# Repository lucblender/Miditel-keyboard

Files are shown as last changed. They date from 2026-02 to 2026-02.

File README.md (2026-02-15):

# MIDITEL, a MIDI keyboard using a Minitel keyboard

Finished Product

# Description

The Miditel is a Midi keyboard built with a Mini-tel keyboard. The key layout is inspired by an accordion keyboard. Its features are highly inspired by the Arturia Keystep including Normal play, sequencer, or arpeggiator. In addition, it embedded a small Oled screen and give unique a multi-sequencer feature

**The project is based on the MINITEL 1.**

# Hardware

You will need a miditel 1 keyboard with a working keyboard matrix, the PCB which can be found in the [hardware/PCB](hardware/PCB), an 1.3 inch [OLED Display module by waveshare](https://www.waveshare.com/1.3inch-oled-module-c.htm)

# Software

The project run on a raspberry pico 1 with micropython. To this date, it is working under v1.27.0. Download latest micropython image on [Micropython website](https://micropython.org/download/RPI_PICO/).

You then need to transfer .py files and .pbm (pictures) files on the little fs of the pico. All the .py files, all the .pbm files and the folder arp_mode with all its .pbm files.
Here is what the structure should look like.

- arp_mode
  - dwn.pbm
  - dwnx2.pbm
  - ...
- arial6.py
- arial8.py
- arial10.py
- font6.py
- font10.py
- keyboardConfiguration.py
- main.py
- OLED_SPI.py
- writer.py
- lxb64x64.pbm
- pause.pbm
- play.pbm
- rec.pbm
- stop.pbm

## About Minitel

Remove the keyboard from your minitel. You will then connect the ribbon cable of the minitel to a serie of wire and then to J3, the 17 pins connector on the PCB. All the info about the minitel keyboard and its matrix can be found on [entropie.org](https://entropie.org/3615/index.php/2020/08/05/le-clavier-du-minitel-1b/)

## Manufacturing Files

### PCB

The PCB to control the miditel files can be found in the [hardware/PCB](hardware/PCB) folder. I personnaly used [PCBWay](https://www.pcbway.com) service to produce the PCB.

The PCB is as simple double sided PCB.

### Front panel

The manufacturing files of the front panel can be found in the [hardware/FrontPanel](hardware/FrontPanel) folder. It has been made to cnc machine and laser engrave a front panel. They can also be easily converted to make the front panel of a PCB which is a cheaper option.
The Front panel is composed of the following files:

- Top_Platev004 files : the front panel with the cutout
- Top_Plate_design-only : only the "aestetic" part
- Top_Plate_outer_shape : only the "cutout" part

In my original design, the front panel has been made using [PCBWay](https://www.pcbway.com) Sheet Metal Fabrication service. I chose bead-blasted copper with custom laser engraving to fit the color of the Minitel Keyboard.

### 3D printed parts

The manufacturing files of the front panel can be found in the [hardware/3DPrinting](hardware/3DPrinting) folder.

- Bottom_Platev004.3mf : bottom plate that hold the PCB and is glued directly on the minitel
- Wheelv004.3mf : wheel to put on the potentiometers
- paint stencil folder : 3d printable stencil to paint white and black square on the key of the minitel

### LICENSE

[CC BY-NC-SA](https://creativecommons.org/licenses/by-nc-sa/4.0/)

This license enables reusers to distribute, remix, adapt, and build upon the material in any medium or format for noncommercial purposes only, and only so long as attribution is given to the creator. If you remix, adapt, or build upon the material, you must license the modified material under identical terms. CC BY-NC-SA includes the following elements:

BY: credit must be given to the creator.
NC: Only noncommercial uses of the work are permitted.
SA: Adaptations must be shared under the same terms.

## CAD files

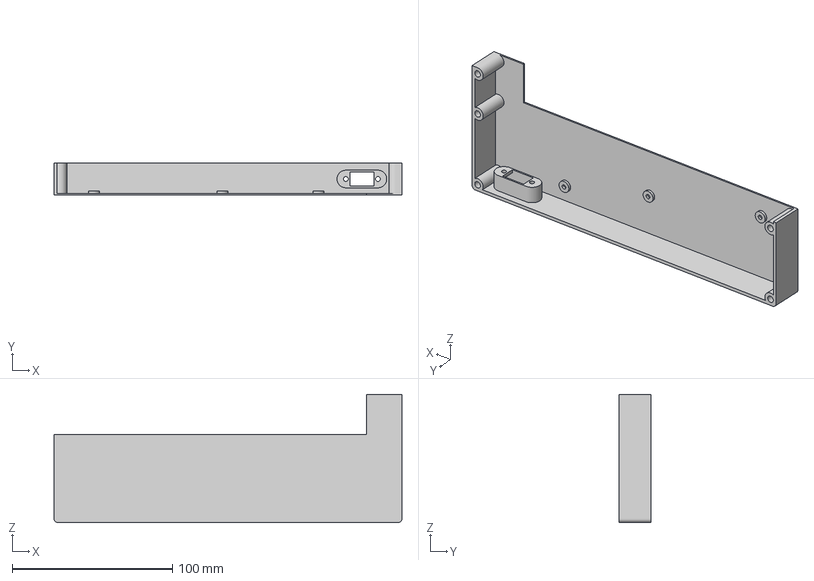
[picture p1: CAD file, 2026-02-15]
hardware/3DPrinting/Bottom_Platev004.3mf
217.0 x 20.0 x 80.0 mm

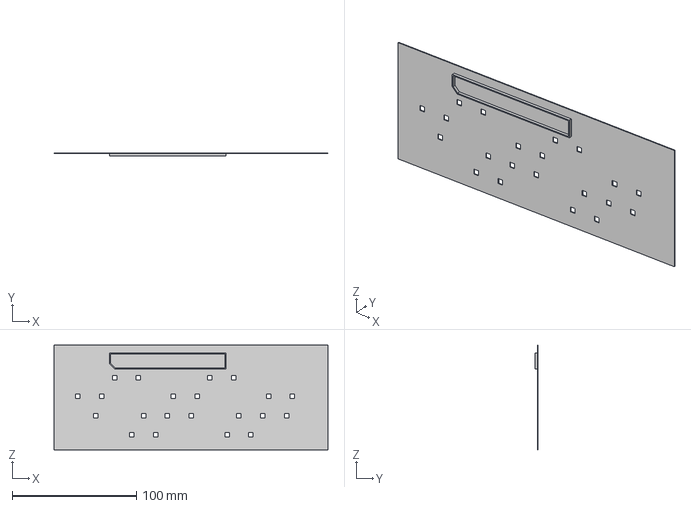
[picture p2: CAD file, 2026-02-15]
hardware/3DPrinting/paint stencil/white_keys_v001.3mf
220.8 x 2.60 x 84.5 mm

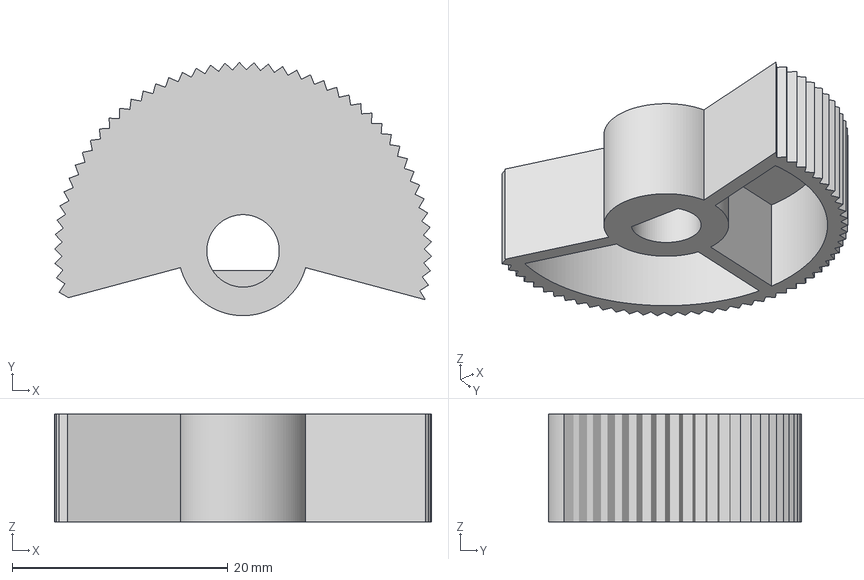
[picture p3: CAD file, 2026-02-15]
hardware/3DPrinting/Wheelv004.3mf
34.9 x 23.5 x 10.0 mm

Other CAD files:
hardware/FrontPanel/Top_Platev004.step
hardware/3DPrinting/paint stencil/black_keys_v001.3mf
hardware/FrontPanel/Top_Plate_design-only_v004.dxf
hardware/FrontPanel/Top_Platev004_outer_shape.dxf
hardware/FrontPanel/Top_Platev004.dxf

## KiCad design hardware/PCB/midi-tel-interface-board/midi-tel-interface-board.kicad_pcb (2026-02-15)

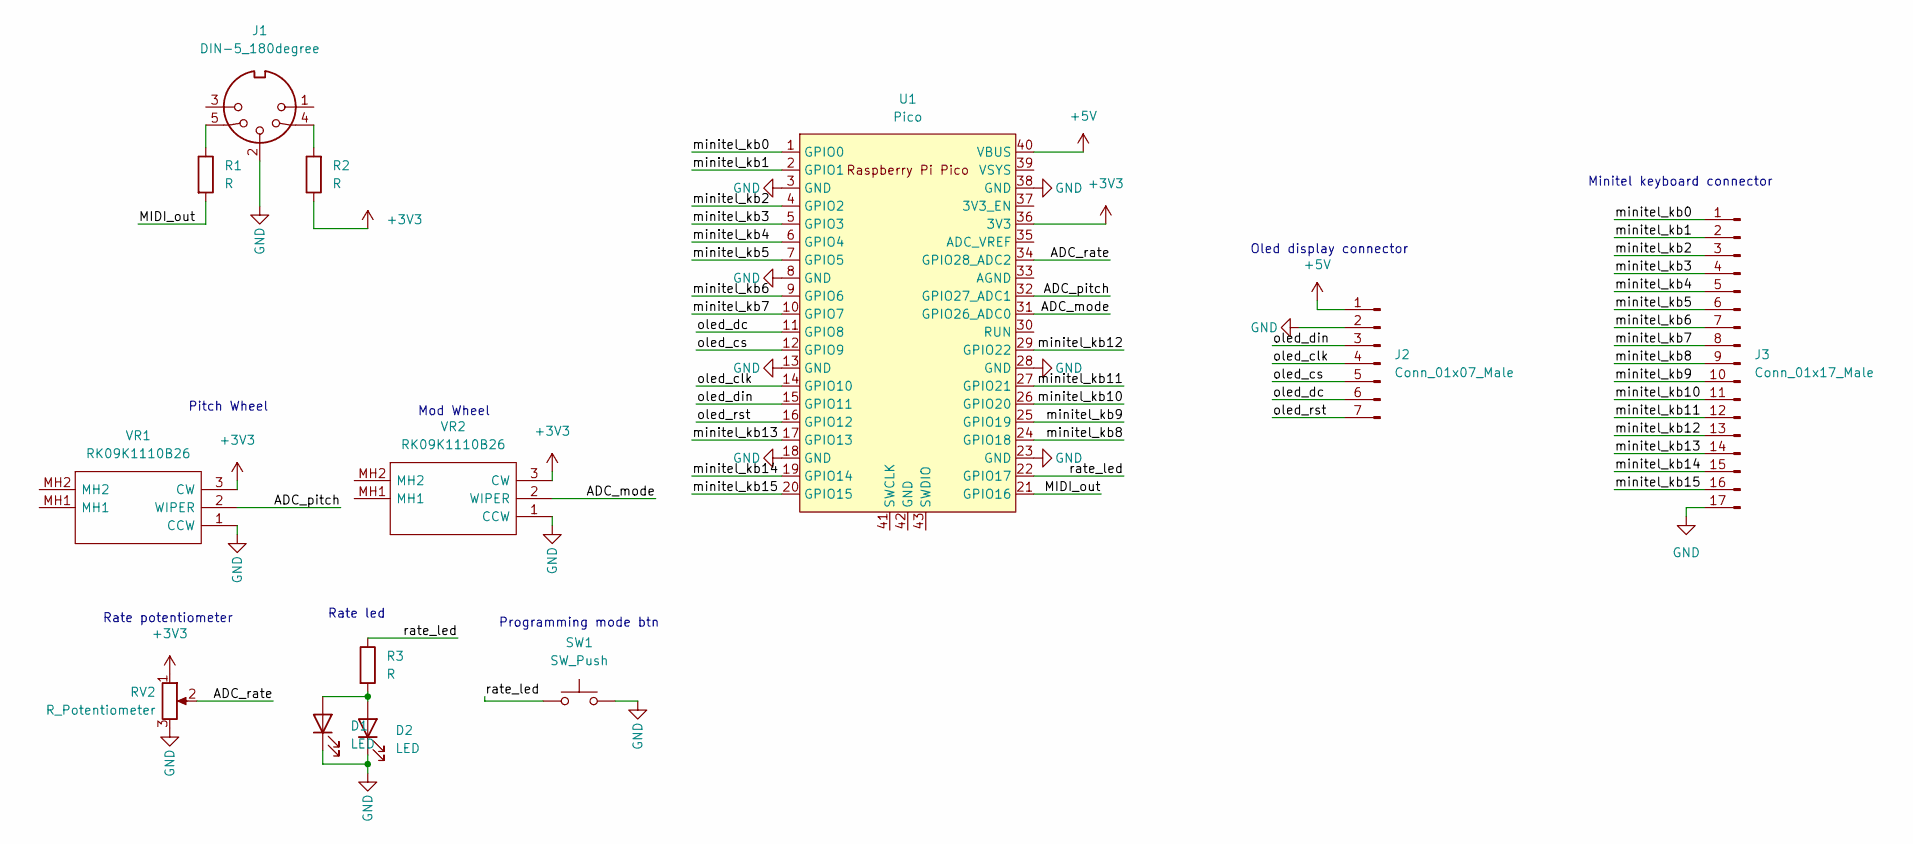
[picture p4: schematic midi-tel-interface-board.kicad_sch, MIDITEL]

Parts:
D1: LED; LED_D3.0mm
D2: LED; LED_0603_1608Metric
J1: DIN-5_180degree; 52120441
J2: Conn_01x07_Male; PinHeader_1x07_P2.54mm_Vertical
J3: Conn_01x17_Male; PinHeader_1x17_P2.54mm_Vertical
R1, R2, R3: R; R_0805_2012Metric
RV2: R_Potentiometer; Potentiometer_Alpha_RD901F-40-00D_Single_Vertical
SW1: SW_Push; SW_PUSH_6mm
U1: Pico; RPi_Pico_SMD_TH
VR1, VR2: RK09K1110B26; Mouser Part Number 688-RK09K1110B26

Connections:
+3V3: R2.1, RV2.1, U1.36 (3V3), VR1.3 (CW), VR2.3 (CW)
+5V: J2.1, U1.40 (VBUS)
/ADC_mode: U1.31 (GPIO26_ADC0), VR2.2 (WIPER)
/ADC_pitch: U1.32 (GPIO27_ADC1), VR1.2 (WIPER)
/ADC_rate: RV2.2, U1.34 (GPIO28_ADC2)
/MIDI_out: R1.2, U1.21 (GPIO16)
/minitel_kb0: J3.1, U1.1 (GPIO0)
/minitel_kb1: J3.2, U1.2 (GPIO1)
/minitel_kb2: J3.3, U1.4 (GPIO2)
/minitel_kb3: J3.4, U1.5 (GPIO3)
/minitel_kb4: J3.5, U1.6 (GPIO4)
/minitel_kb5: J3.6, U1.7 (GPIO5)
/minitel_kb6: J3.7, U1.9 (GPIO6)
/minitel_kb7: J3.8, U1.10 (GPIO7)
/minitel_kb8: J3.9, U1.24 (GPIO18)
/minitel_kb9: J3.10, U1.25 (GPIO19)
/minitel_kb10: J3.11, U1.26 (GPIO20)
/minitel_kb11: J3.12, U1.27 (GPIO21)
/minitel_kb12: J3.13, U1.29 (GPIO22)
/minitel_kb13: J3.14, U1.17 (GPIO13)
/minitel_kb14: J3.15, U1.19 (GPIO14)
/minitel_kb15: J3.16, U1.20 (GPIO15)
/oled_clk: J2.4, U1.14 (GPIO10)
/oled_cs: J2.5, U1.12 (GPIO9)
/oled_dc: J2.6, U1.11 (GPIO8)
/oled_din: J2.3, U1.15 (GPIO11)
/oled_rst: J2.7, U1.16 (GPIO12)
/rate_led: R3.1, SW1.1, U1.22 (GPIO17)
GND: D1.1 (K), D2.1 (K), J1.2, J2.2, J3.17, RV2.3, SW1.2, U1.3 (GND), U1.8 (GND), U1.13 (GND), U1.18 (GND), U1.23 (GND), U1.28 (GND), U1.38 (GND), VR1.1 (CCW), VR2.1 (CCW)
unnamed: D1.2 (A), D2.2 (A), R3.2
unnamed: J1.4, R2.2
unnamed: J1.5, R1.1

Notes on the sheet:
Mod Wheel
Oled display connector
Programming mode btn
Rate led
Rate potentiometer
Pitch Wheel
Minitel keyboard connector

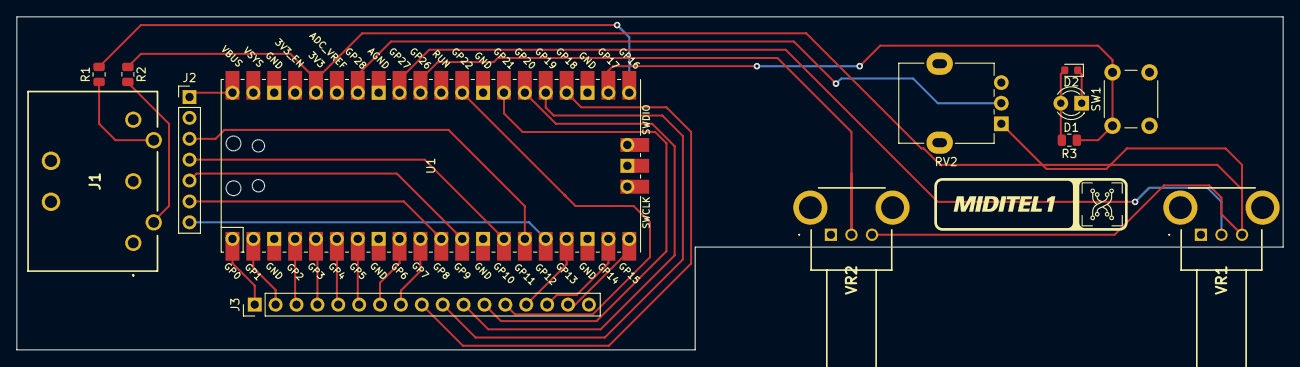
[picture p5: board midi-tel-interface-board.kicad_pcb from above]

Board: 2 copper layers, 154.0 x 40.5 mm, 13 parts (0 on the bottom side), 32 nets.

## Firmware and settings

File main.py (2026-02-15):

import machine
from machine import Pin
import utime
import time
import _thread

from keyboardConfiguration import KeyboardConfiguration, append_error
from OLED_SPI import OLED_1inch3

from machine import freq
freq(250_000_000, 250_000_000)

boot_exit_button = Pin(17, Pin.IN, Pin.PULL_UP)
rate_potentiometer = machine.ADC(28)
pitch_potentiometer = machine.ADC(27)
mod_potentiometer = machine.ADC(26)

COL_NUMBER = 8
ROW_NUMBER = 8

MAX_DELAY_BEFORE_SCREENSAVER_S = 300
last_key_update = time.time()


# 0 1 2 3 4 5 6 7 8 9 10 11 12 13 14 15
# F E D C B A 9 8 7 6 5  4  3  2  1  0

# line = 1  2  3  4  B C D E
#        14 13 12 11 4 3 2 1

# col =  0  5  6 7 8 9 A F
#        15 10 9 8 7 6 5 0


# 8 9  10 11 12
# 22 21 20 19 18

col_list_pin = [15, 20, 21, 22, 7, 6, 5, 0]
row_list_pin = [14, 13, 18, 19, 4, 3, 2, 1]
# invertedd col_list_pin=[0,5,6,7,22,21,20,15]
# inverted row_list_pin=[1,2,3,4,19,18,13,14]
row_list = [0, 0, 0, 0, 0, 0, 0, 0]
col_list = [0, 0, 0, 0, 0, 0, 0, 0]

smooth_rate_potentiometer = -1
smooth_mod_potentiometer = -1
smooth_pitch_potentiometer = -1

for x in range(0, ROW_NUMBER):
    row_list[x] = Pin(row_list_pin[x], Pin.OUT)
    row_list[x].value(1)


for x in range(0, COL_NUMBER):
    col_list[x] = Pin(col_list_pin[x], Pin.IN, Pin.PULL_UP)

key_map = [
    ["up", "t", "g", ".", "b", "guide", "Fnct", "connexion fin"],
    ["correction", "e", "d", "Esc", "c", "z", "s", "x"],
    ["annulation", "r", "f", ",", "v", "a", "q", "w"],
    ["down", "y", "h", "'", "n", "sommaire", "Ctrl", "espace"],
    ["shift", ";", "*", "suite", "0", "u", "j", "#"],
    ["left", "-", "7", "retour", "8", "i", "k", "9"],
    ["right", ":", "4", "envoi", "5", "o", "l", "6"],
    ["enter", "?", "1", "répétition", "2", "p", "m", "3"]
]

note_map = [
    [0, 65, 67, 60, 69, 0, 0, 0],
    [0, 59, 61, 54, 63, 56, 58, 60],
    [0, 62, 64, 57, 66, 53, 55, 57],
    [0, 68, 70, 63, 72, 0, 52, 0],
    [54, 66, 0, 0, 0, 71, 73, 0],
    [0, 69, 0, 0, 0, 74, 76, 0],
    [0, 72, 0, 0, 0, 77, 79, 0],
    [0, 75, 0, 0, 0, 80, 82, 0]
]

key_state = [[0, 0, 0, 0, 0, 0, 0, 0], [0, 0, 0, 0, 0, 0, 0, 0], [0, 0, 0, 0, 0, 0, 0, 0], [0, 0, 0, 0, 0, 0, 0, 0], [
    0, 0, 0, 0, 0, 0, 0, 0], [0, 0, 0, 0, 0, 0, 0, 0], [0, 0, 0, 0, 0, 0, 0, 0], [0, 0, 0, 0, 0, 0, 0, 0]]
key_state_old = [[0, 0, 0, 0, 0, 0, 0, 0], [0, 0, 0, 0, 0, 0, 0, 0], [0, 0, 0, 0, 0, 0, 0, 0], [0, 0, 0, 0, 0, 0, 0, 0], [
    0, 0, 0, 0, 0, 0, 0, 0], [0, 0, 0, 0, 0, 0, 0, 0], [0, 0, 0, 0, 0, 0, 0, 0], [0, 0, 0, 0, 0, 0, 0, 0]]

keyboard_config = KeyboardConfiguration()
OLED = OLED_1inch3(keyboard_config)
keyboard_config.set_display(OLED)


def KeypadRead(cols, rows):
    global key_state
    global key_state_old
    global last_key_update
    global OLED

    key_state = [[0, 0, 0, 0, 0, 0, 0, 0], [0, 0, 0, 0, 0, 0, 0, 0], [0, 0, 0, 0, 0, 0, 0, 0], [0, 0, 0, 0, 0, 0, 0, 0], [
        0, 0, 0, 0, 0, 0, 0, 0], [0, 0, 0, 0, 0, 0, 0, 0], [0, 0, 0, 0, 0, 0, 0, 0], [0, 0, 0, 0, 0, 0, 0, 0]]

    for r in range(0, ROW_NUMBER):
        # put pin as output
        Pin(row_list_pin[r], Pin.OUT)
        rows[r].value(0)
        for c in range(0, COL_NUMBER):
            if cols[c].value() == 0:
                key_state[r][c] = 1

            if (key_state[r][c] != key_state_old[r][c]):
                last_key_update = time.time()
                if OLED.is_screensaver() == True:
                    OLED.reset_screensaver_mode()
                key = key_map[r][c]
                note = note_map[r][c]
                if key_state[r][c] == 0:
                    if (note != 0):
                        keyboard_config.note_off(
                            note+keyboard_config.octave_offset*12)
                    else:
                        customKeyOff(key)
                else:
                    if (note != 0):
                        keyboard_config.note_on(
                            note+keyboard_config.octave_offset*12)
                    else:
                        customKeyOn(key)
        # put pin as input to have high z
        Pin(row_list_pin[r], Pin.IN)

    for x in range(0, COL_NUMBER):
        for y in range(0, ROW_NUMBER):
            key_state_old[x][y] = key_state[x][y]


print("--- Ready to get user inputs ---")


def customKeyOn(key):
    global octaveOffset
    if key == "right":
        keyboard_config.incr_octave_offset()
    elif key == "left":
        keyboard_config.decr_octave_offset()
    if key == "up":
        keyboard_config.incr_mode()
    elif key == "down":
        keyboard_config.decr_mode()
    elif key == "guide":
        keyboard_config.rec_pressed()
    elif key == "correction":
        keyboard_config.stop_pressed()
    elif key == "suite":
        keyboard_config.pauseplay_pressed()
    elif key == "envoi":
        keyboard_config.load_seq_pressed()
    elif key == "enter":
        keyboard_config.blank_tile_pressed()
    elif key == "sommaire":
        keyboard_config.midi_channel_gate_length_pressed()
    elif key == "#":
        keyboard_config.sharp_pressed()
    elif key == "*":
        keyboard_config.star_pressed()
    elif key == "annulation":
        keyboard_config.clear_seq_hold_pressed()
    elif key == "retour":
        keyboard_config.decr_arp_mode_kbp_transpose()
    elif key == "répétition":
        keyboard_config.incr_arp_mode_undo_seq()
    elif key == "connexion fin":
        keyboard_config.change_time_div_pressed()
    elif key == "espace":
        keyboard_config.note_on(69)  # play A4 440Hz
    elif key.isdigit():
        keyboard_config.digit_pressed(int(key))


def customKeyOff(key):
    if key == "espace":
        keyboard_config.note_off(69)


def refresh_screen_loop():
    global OLED
    index = 0
    while True:
        if OLED.is_screensaver() == True:
            index += 1
            if index % 16 == True:
                OLED.update_screensaver()
                index = 0
        elif (OLED.need_refresh_flag == True):
            OLED.display()
        time.sleep(0.01)


if boot_exit_button.value() == 1:
    try:
        OLED.display_helixbyte()
        time.sleep(0.5)
        keyboard_config.set_led(Pin(17, Pin.OUT))
        keyboard_config.display()
        _thread.start_new_thread(refresh_screen_loop, ())
        OLED.need_screen_refresh()

        while True:
            if time.time() - last_key_update > MAX_DELAY_BEFORE_SCREENSAVER_S and OLED.is_screensaver() == False:
                OLED.set_screensaver_mode()

            key = KeypadRead(col_list, row_list)
            if smooth_rate_potentiometer == -1:
                smooth_rate_potentiometer = (
                    65536-rate_potentiometer.read_u16())
            else:
                smooth_rate_potentiometer = smooth_rate_potentiometer * \
                    0.8 + 0.2*(65536-rate_potentiometer.read_u16())

            if smooth_mod_potentiometer == -1:
                smooth_mod_potentiometer = (65536-mod_potentiometer.read_u16())
            else:
                smooth_mod_potentiometer = smooth_mod_potentiometer * \
                    0.5 + 0.5*(65536-mod_potentiometer.read_u16())

            if smooth_pitch_potentiometer == -1:
                smooth_pitch_potentiometer = (
                    65536-pitch_potentiometer.read_u16())
            else:
                smooth_pitch_potentiometer = smooth_pitch_potentiometer * \
                    0.5 + 0.5*(65536-pitch_potentiometer.read_u16())

            keyboard_config.set_rate_potentiometer(smooth_rate_potentiometer)
            keyboard_config.set_pitch_potentiometer(smooth_pitch_potentiometer)
            keyboard_config.set_mod_potentiometer(smooth_mod_potentiometer)
    except Exception as e:
        keyboard_config.deinit_timer()
        append_error(e)
else:
    keyboard_config.deinit_timer()
    OLED.display_helixbyte()
    time.sleep(0.5)
    OLED.display_programming_mode()
    print("Exit button pressed at boot, quit program")

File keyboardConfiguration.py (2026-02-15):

import machine
from machine import Pin, Timer
import ustruct
from random import randrange
import json

MIN_BPM = 30
MAX_BPM = 240

LEN_INDEX = -1

POT_MAX_VALUE = 42000
POT_MIN_VALUE = 24000
POT_INTERVAL_VALUE = POT_MAX_VALUE-POT_MIN_VALUE

# Lookup tables for O(1) performance instead of if-elif chains
# Indexed by TimeDiv enum values
TIME_DIV_TO_SPLIT = (24, 16, 12, 8, 6, 4, 3, 2)
TIME_DIV_TO_STR = ("1/4", "1/4T", "1/8", "1/8T",
                   "1/16", "1/16T", "1/32", "1/32T")
MODE_TO_STR = ("Basic", "Arpeg", "Sequ", "Multi\nsequencer")
ARP_MODE_TO_STR = ("Up", "Down", "Inclusive", "Exclusive",
                   "Random", "Press Order", "Up x2", "Down x2")
PLAY_MODE_TO_STR = ("⏵", "⏸", "⏺", "⏹")


def enum(**enums: int):
    return type('Enum', (), enums)


Mode = enum(BASIC=0, ARPEGIATOR=1, SEQUENCER=2, MULTISEQUENCER=3)

TimeDiv = enum(ONE_FOURTH=0,
               ONE_FOURTH_T=1,
               ONE_EIGHTH=2,
               ONE_EIGHTH_T=3,
               ONE_SIXTEENTH=4,
               ONE_SIXTEENTH_T=5,
               ONE_THIRTYSECOND=6,
               ONE_THIRTYSECOND_T=7)


PlayMode = enum(PLAYING=0,
                PAUSING=1,
                RECORDING=2,
                STOPPED=3)

ArpMode = enum(UP=0,
               DWN=1,
               INC=2,
               EXC=3,
               RAND=4,
               ORDER=5,
               UPX2=6,
               DWNX2=7,
               )


def modeToStr(local_mode):
    return MODE_TO_STR[local_mode]


def timeDivToStr(local_time_div):
    return TIME_DIV_TO_STR[local_time_div]


def timeDivToTimeSplit(local_time_div):
    return TIME_DIV_TO_SPLIT[local_time_div]


def arpModeToStr(local_arp_mode):
    return ARP_MODE_TO_STR[local_arp_mode]


def sort_notes_for_arp_mode(local_arp_mode, arp_notes):
    to_return = []
    cpy_arp_notes = list(arp_notes)

    if local_arp_mode == ArpMode.UP:
        cpy_arp_notes.sort()
        to_return = cpy_arp_notes
    elif local_arp_mode == ArpMode.DWN:
        cpy_arp_notes.sort()
        cpy_arp_notes.reverse()
        to_return = cpy_arp_notes
    elif local_arp_mode == ArpMode.INC:
        cpy_arp_notes.sort()
        rev_cpy_arp_notes = list(cpy_arp_notes)
        rev_cpy_arp_notes.reverse()
        to_return = cpy_arp_notes+rev_cpy_arp_notes
    elif local_arp_mode == ArpMode.EXC:
        cpy_arp_notes.sort()
        rev_cpy_arp_notes = list(cpy_arp_notes)
        rev_cpy_arp_notes.reverse()
        to_return = cpy_arp_notes+rev_cpy_arp_notes[1:-1]
    # in random, the index of the note played will be random, the array doesn't change
    elif local_arp_mode == ArpMode.RAND:
        to_return = cpy_arp_notes
    elif local_arp_mode == ArpMode.ORDER:
        to_return = cpy_arp_notes
    elif local_arp_mode == ArpMode.UPX2:
        cpy_arp_notes.sort()
        for x in cpy_arp_notes:
            to_return.append(x)
            to_return.append(x)
    elif local_arp_mode == ArpMode.DWNX2:
        cpy_arp_notes.sort()
        cpy_arp_notes.reverse()
        for x in cpy_arp_notes:
            to_return.append(x)
            to_return.append(x)
    return to_return


def playModeToStr(local_play_mode):
    return PLAY_MODE_TO_STR[local_play_mode]


def midi_to_key(note_num):
    notes = ["C", "C#", "D", "D#", "E", "F", "F#", "G", "G#", "A", "A#", "B"]
    octave = (note_num // 12) - 1
    key = notes[note_num % 12] + str(octave)
    return key


def append_error(error):
    print("*-"*20)
    print("Error caught")
    print(error)
    print("*-"*20)
    error_file = open("error.txt", "a")
    error_file.write(str(error))
    error_file.write("\n")
    error_file.close()


def decomp(n):
    L = dict()
    k = 2
    while n != 1:
        exp = 0
        while n % k == 0:
            n = n // k
            exp += 1
        if exp != 0:
            L[k] = exp
        k = k + 1
    return L


def _ppcm(a, b):
    Da = decomp(a)
    Db = decomp(b)
    p = 1
    for facteur, exposant in Da.items():
        if facteur in Db:
            exp = max(exposant, Db[facteur])
        else:
            exp = exposant
        p *= facteur**exp
    for facteur, exposant in Db.items():
        if facteur not in Da:
            p *= facteur**exposant
    return p


def ppcm(L):
    while len(L) > 1:
        a = L[-1]
        L.pop()
        b = L[-1]
        L.pop()
        L.append(_ppcm(a, b))
    return L[0]


"""
if self.mode == Mode.BASIC:
    pass
elif self.mode == Mode.SEQUENCER:
    pass
elif self.mode == Mode.ARPEGIATOR:
    pass
"""
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

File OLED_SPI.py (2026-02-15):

from machine import Pin, SPI
import framebuf
import time
from keyboardConfiguration import *
import arial6
import arial8
import arial10
import font10
import font6
import writer
from random import randrange

DC = 8
RST = 12
MOSI = 11
SCK = 10
CS = 9


def pict_to_fbuff(path, x, y):
    with open(path, 'rb') as f:
        f.readline()  # Magic number
        f.readline()  # Creator comment
        f.readline()  # Dimensions
        data = bytearray(f.read())
    return framebuf.FrameBuffer(data, x, y, framebuf.MONO_HLSB)


class OLED_1inch3(framebuf.FrameBuffer):
    def __init__(self, keyboard_config):
        self.width = 128
        self.height = 64

        self.need_refresh_flag = False

        self.screensaver_active = False
        self.screesaver_pixels = [[0]*2]*20

        self.cs = Pin(CS, Pin.OUT)
        self.rst = Pin(RST, Pin.OUT)

        self.cs(1)
        self.spi = SPI(1)
        self.spi = SPI(1, 4_000_000)
        self.spi = SPI(1, 4_000_000, polarity=0, phase=0,
                       sck=Pin(SCK), mosi=Pin(MOSI), miso=None)
        self.dc = Pin(DC, Pin.OUT)
        self.dc(1)
        self.buffer = bytearray(self.height * self.width // 8)
        super().__init__(self.buffer, self.width, self.height, framebuf.MONO_HMSB)
        self.init_display()

        self.white = 0xffff
        self.black = 0x0000

        self.keyboard_config = keyboard_config

        self.font_writer_arial6 = writer.Writer(self, arial6)
        self.font_writer_arial8 = writer.Writer(self, arial8)
        self.font_writer_arial10 = writer.Writer(self, arial10)
        self.font_writer_font10 = writer.Writer(self, font10)
        self.font_writer_font6 = writer.Writer(self, font6)

        self.fbuf_play = pict_to_fbuff('play.pbm', 9, 9)
        self.fbuf_pause = pict_to_fbuff('pause.pbm', 9, 9)
        self.fbuf_rec = pict_to_fbuff('rec.pbm', 9, 9)
        self.fbuf_stop = pict_to_fbuff('stop.pbm', 9, 9)

        self.fbufs_play_mode = [self.fbuf_play,
                                self.fbuf_pause, self.fbuf_rec, self.fbuf_stop]

        self.fbuf_arp_up = pict_to_fbuff('arp_mode/up.pbm', 16, 16)
        self.fbuf_arp_dwn = pict_to_fbuff('arp_mode/dwn.pbm', 16, 16)
        self.fbuf_arp_inc = pict_to_fbuff('arp_mode/inc.pbm', 16, 16)
        self.fbuf_arp_exc = pict_to_fbuff('arp_mode/exc.pbm', 16, 16)
        self.fbuf_arp_rand = pict_to_fbuff('arp_mode/rand.pbm', 16, 16)
        self.fbuf_arp_order = pict_to_fbuff('arp_mode/order.pbm', 16, 16)
        self.fbuf_arp_upx2 = pict_to_fbuff('arp_mode/upx2.pbm', 16, 16)
        self.fbuf_arp_dwnx2 = pict_to_fbuff('arp_mode/dwnx2.pbm', 16, 16)

        self.fbufs_arp_modes = [self.fbuf_arp_up, self.fbuf_arp_dwn, self.fbuf_arp_inc, self.fbuf_arp_exc,
                                self.fbuf_arp_rand, self.fbuf_arp_order, self.fbuf_arp_upx2, self.fbuf_arp_dwnx2]

        self.fbuf_inv_arp_up = pict_to_fbuff('arp_mode/inv_up.pbm', 16, 16)
        self.fbuf_inv_arp_dwn = pict_to_fbuff('arp_mode/inv_dwn.pbm', 16, 16)
        self.fbuf_inv_arp_inc = pict_to_fbuff('arp_mode/inv_inc.pbm', 16, 16)
        self.fbuf_inv_arp_exc = pict_to_fbuff('arp_mode/inv_exc.pbm', 16, 16)
        self.fbuf_inv_arp_rand = pict_to_fbuff('arp_mode/inv_rand.pbm', 16, 16)
        self.fbuf_inv_arp_order = pict_to_fbuff(
            'arp_mode/inv_order.pbm', 16, 16)
        self.fbuf_inv_arp_upx2 = pict_to_fbuff('arp_mode/inv_upx2.pbm', 16, 16)
        self.fbuf_inv_arp_dwnx2 = pict_to_fbuff(
            'arp_mode/inv_dwnx2.pbm', 16, 16)

        self.fbufs_inv_arp_modes = [self.fbuf_inv_arp_up, self.fbuf_inv_arp_dwn, self.fbuf_inv_arp_inc, self.fbuf_inv_arp_exc,
                                    self.fbuf_inv_arp_rand, self.fbuf_inv_arp_order, self.fbuf_inv_arp_upx2, self.fbuf_inv_arp_dwnx2]

    def write_cmd(self, cmd):
        self.cs(1)
        self.dc(0)
        self.cs(0)
        self.spi.write(bytearray([cmd]))
        self.cs(1)

    def write_data(self, buf):
        self.cs(1)
        self.dc(1)
        self.cs(0)
        self.spi.write(bytearray([buf]))
        self.cs(1)

    def need_screen_refresh(self):
        self.need_refresh_flag = True

    def init_display(self):
        """Initialize dispaly"""
        self.rst(1)
        time.sleep(0.001)
        self.rst(0)
        time.sleep(0.001)
        self.rst(1)

        self.write_cmd(0xAE)  # turn off OLED display

        self.write_cmd(0x00)  # set lower column address
        self.write_cmd(0x10)  # set higher column address

        self.write_cmd(0xB0)  # set page address

        self.write_cmd(0xdc)  # et display start line
        self.write_cmd(0x00)
        self.write_cmd(0x81)  # contract control
        self.write_cmd(0x6f)  # 128
        self.write_cmd(0x21)    # Set Memory addressing mode (0x20/0x21) #

        self.write_cmd(0xa0)  # set segment remap
        self.write_cmd(0xc0)  # Com scan direction
        self.write_cmd(0xa4)  # Disable Entire Display On (0xA4/0xA5)

        self.write_cmd(0xa6)  # normal / reverse
        self.write_cmd(0xa8)  # multiplex ratio
        self.write_cmd(0x3f)  # duty = 1/64

        self.write_cmd(0xd3)  # set display offset
        self.write_cmd(0x60)

        self.write_cmd(0xd5)  # set osc division
        self.write_cmd(0x41)

        self.write_cmd(0xd9)  # set pre-charge period
        self.write_cmd(0x22)

        self.write_cmd(0xdb)  # set vcomh
        self.write_cmd(0x35)

        self.write_cmd(0xad)  # set charge pump enable
        self.write_cmd(0x8a)  # Set DC-DC enable (a=0:disable; a=1:enable)
        self.write_cmd(0XAF)

    def show(self):
        self.write_cmd(0xb0)
        for page in range(0, 64):
            self.column = 63 - page
            self.write_cmd(0x00 + (self.column & 0x0f))
            self.write_cmd(0x10 + (self.column >> 4))
            for num in range(0, 16):
                self.write_data(self.buffer[page*16+num])

    def is_screensaver(self):
        return self.screensaver_active

    def set_screensaver_mode(self):
        self.screensaver_active = True
        for i in range(0, len(self.screesaver_pixels)):
            self.screesaver_pixels[i] = [randrange(0, 128), randrange(0, 64)]

    def reset_screensaver_mode(self):
        self.screensaver_active = False
        self.need_screen_refresh()

    def update_screensaver(self):

        for i in range(0, len(self.screesaver_pixels)):
            self.screesaver_pixels[i][1] += 1
            if self.screesaver_pixels[i][1] > 63:
                self.screesaver_pixels[i] = [randrange(0, 128), 0]
        self.fill(self.black)

        for pix in self.screesaver_pixels:
            self.rect(pix[0], pix[1], 1, 1, self.white)

        self.show()
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

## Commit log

2023-01-15 inverted rows and collumn, works better for polyphony + exit button
    [main.py]
2023-01-22 put rate led and reset button on same pin
2023-01-22 add "space" to play 440hz and make possible to play during stop mode
2023-01-22 add kicad pcb
    [midi-tel-interface-board.kicad_pcb, midi-tel-interface-board.kicad_sch]
2023-01-22 first rough version of pcb
    [midi-tel-interface-board.kicad_pcb, midi-tel-interface-board.kicad_sch]
2023-01-29 add mod and pitch bend wheel
2023-01-29 update gitignore and pcb files
    [midi-tel-interface-board.kicad_pcb, midi-tel-interface-board.kicad_sch]
2023-01-31 add error management and start multi-sequencer mode
    [OLED_SPI.py, keyboardConfiguration.py, main.py]
2023-02-18 put frequency and not period in timer, made timer more stable
2023-07-31 fix midi channel and play note when doing sequence recording
    [keyboardConfiguration.py]
2025-11-17 fix: remove unnecessary screensaver setup
    [OLED_SPI.py]
2026-02-15 fix: put 17 pin connectors for keyboard matrix
    [midi-tel-interface-board.kicad_pcb, midi-tel-interface-board.kicad_sch]
2026-02-15 feature: add front panel files
    [Top_Plate_design-only_v004.dxf, Top_Plate_design-shape_v004.dxf, Top_Platev004.dxf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]
2026-02-15 feature: add 3d printing files
    [Bottom_Platev004.3mf, Wheelv004.3mf, black_keys_v001.3mf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]
2026-02-15 feature: cleanup doc
    [Top_Plate_design-shape_v004.dxf, Top_Platev004.dxf, Top_Platev004_outer_shape.dxf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]
